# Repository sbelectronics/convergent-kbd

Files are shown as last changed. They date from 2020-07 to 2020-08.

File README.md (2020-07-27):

# PS2 Keyboard to Convergent Technologies NGEN Keyboard Adapter

Scott Baker, http://www.smbaker.com/

## Purpose

This is an adapter that lets you use a PS2 keyboard on a Convergent Technologies NGEN workstation. Most of these workstations date to the 80s or 90s. The keyboard interface is a 1200 baud serial protocol that is unique to this architecture, making it problematic to get these old computers working unless you also happen to have the appropriate keyboard.

This adapter allows you to use a PS2 keyboard, which are readily available.

## Convergent special-purpose function keys

The Convergent includes a series of special-purpose keys on the left side of the keyboard. These include keys like the "Help" key, the "Cancel" and "Finish" keys, "Action", etc. Most of these I've attempted to emulate with other keys on a 104 key PS2 keyboard.

I also added the ability to build the adapter with a set of 12 Cherry MX keys. This gives a more Convergent-like feel to the keyboard rather than trying to hunt down bizarre mappings on 104 key keyboard. These additional keys are entirely optional -- you can build the adapter with or without them.

## My first prototype, using ATTINY85

My first prototype used an ATTINY85 processor. I've kept the code in this repo for historical reasons. This adapter was compact, but had a few functionality issues due to the need to implement a software UART -- it was possible to hit the PS2 keyboard fast enough to eventually cause the serial and/or PS2 timing to glitch and register an incorrect keyboard event. Maybe with some work that would be fixable, but switching to a microcontroller with a real UART was a better solution.

## My second (and final) prototype using ATMEGA328

This version used an ATMEGA328, which has a hardware UART. Much simpler and more reliably than trying to make do with software UART. The 328 also has a number of additional GPIO, which I used to implement the 12 additional special-function keys. There were enough spare GPIO that I didn't bother to multiplex the keyboard scanning.

This is the prototype you want to build -- it's in the `convergent-keyboard-at328` directory.

## Fuses

Make sure to burn the fuses in addition to burning the code. The fuses are generally at the defaults with the exception of CKDIV8. There's a screenshot of the fuse settings in minipro.

## Schematics

The Schematics are in the schematics directory. My blog post at https://www.smbaker.com/restoring-a-convergent-technologies-ngen-pc-workstation-burroughs-b25-unisys has a lot more detail on the design work, both on the keyboard adapter and on a video adapter.

The schematics are checked in here into the "schematics" directory. You'll find two schematics, one for the adapter with 4 optional special-function keys, and another for an addon board that adds the remaining 8 special-function keys. As mentioned above, the keys are optional. This was split into two boards to make the board production cost-effective (two small boards can be ordered as "prototypes" whereas one large board must be ordered as production, from the board house that I use).

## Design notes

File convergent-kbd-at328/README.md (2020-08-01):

Board: Atmega328 on a breadboard

Makefile notes:
   Makefile is highly customized to my home setup.
   You'll need to update it for your paths.

   "make help"  -- shows the help
   "make show_boards" -- shows the boards
   "make" -- makes everything
   "make ispload" -- burns using the usbasp
   "make set_fuses" -- burns the fuses

   My arduino directory has "atmega328 on a breadboard" manually copied into the tree.

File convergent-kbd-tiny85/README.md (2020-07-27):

Board: AtTiny25/45/85
Chip: AtTiny85
Clock: 8Mhz (Excernal)    (should be internal??)
Bod Level: Bod Disabled
Save Eeprom: Eeporm retained
Timer 1 Clock: CPU
LTO: Disabled

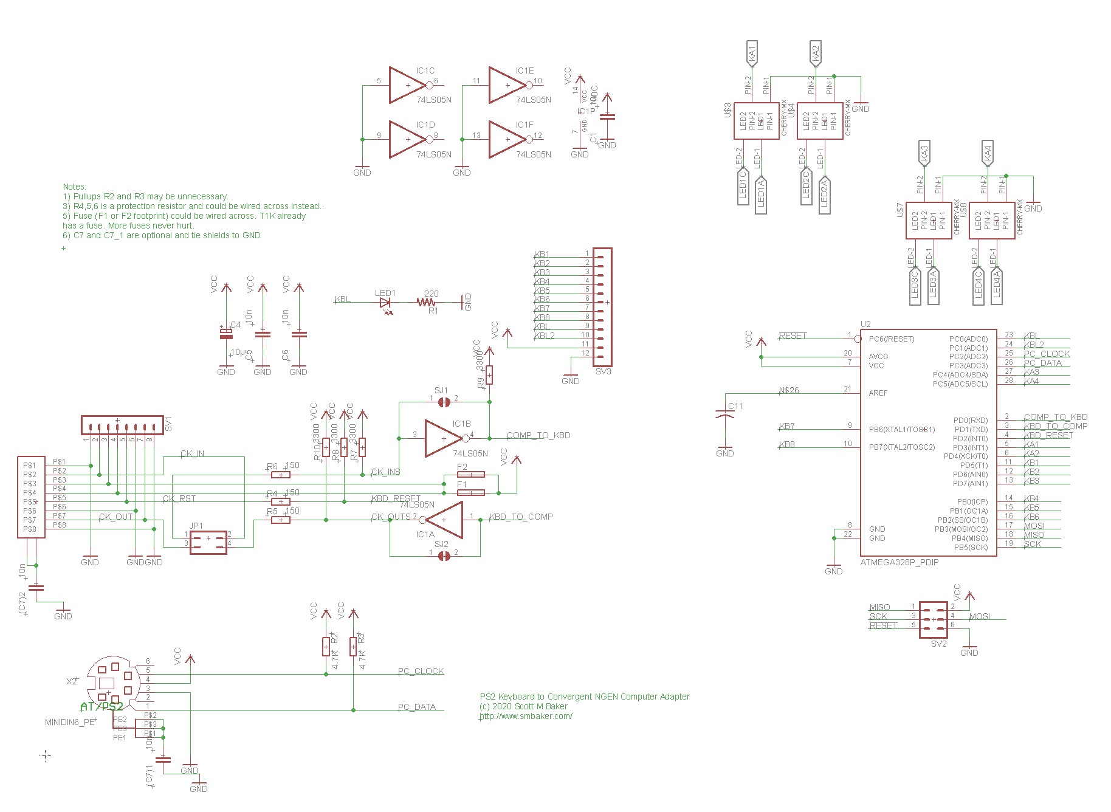
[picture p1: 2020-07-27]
schematics/convergent-keypad-at328-rev0.4.jpg

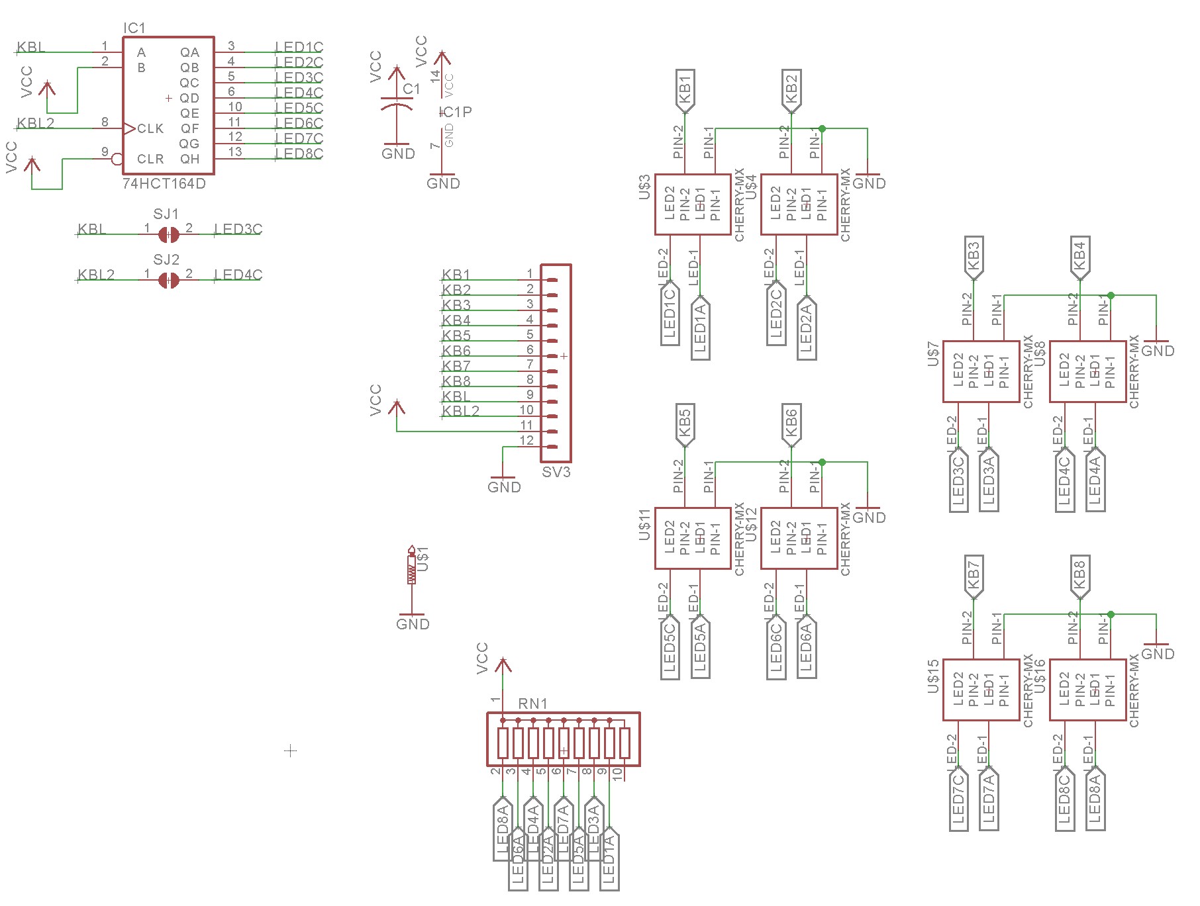
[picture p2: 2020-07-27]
schematics/8key-addon-schematic.jpg

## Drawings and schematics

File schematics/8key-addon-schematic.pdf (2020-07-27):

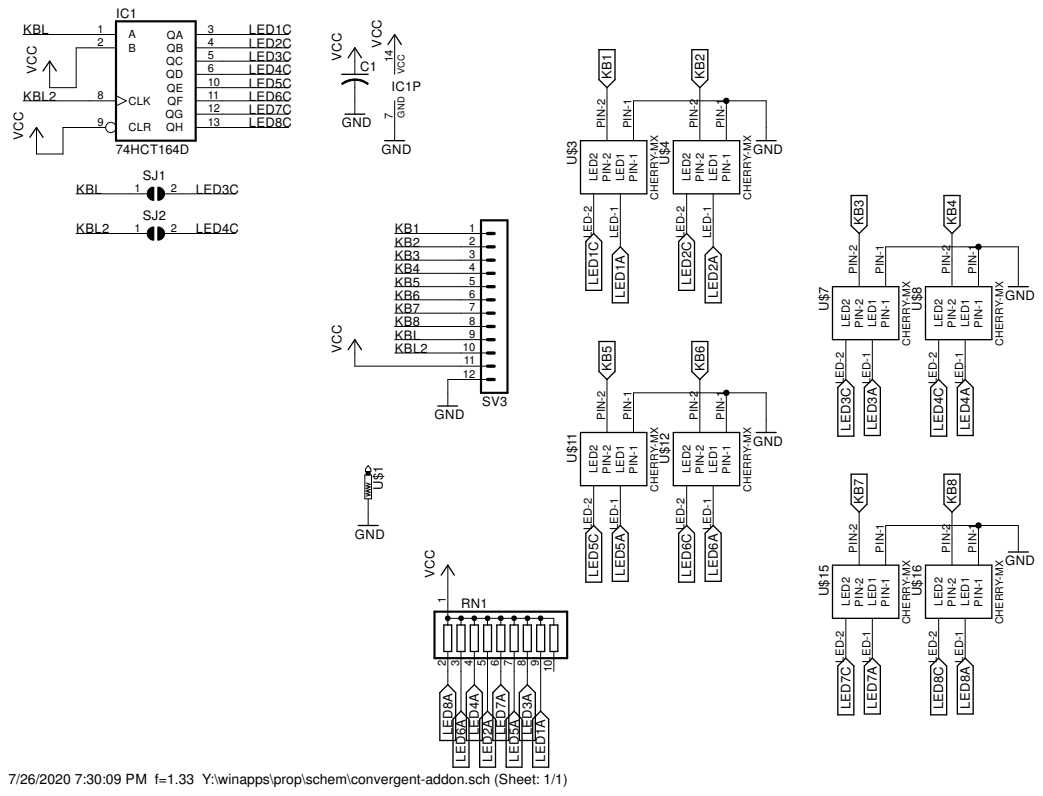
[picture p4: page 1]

7/26/2020 7:30:09 PM f=1.33 Y:\winapps\prop\schem\convergent-addon.sch (Sheet: 1/1)

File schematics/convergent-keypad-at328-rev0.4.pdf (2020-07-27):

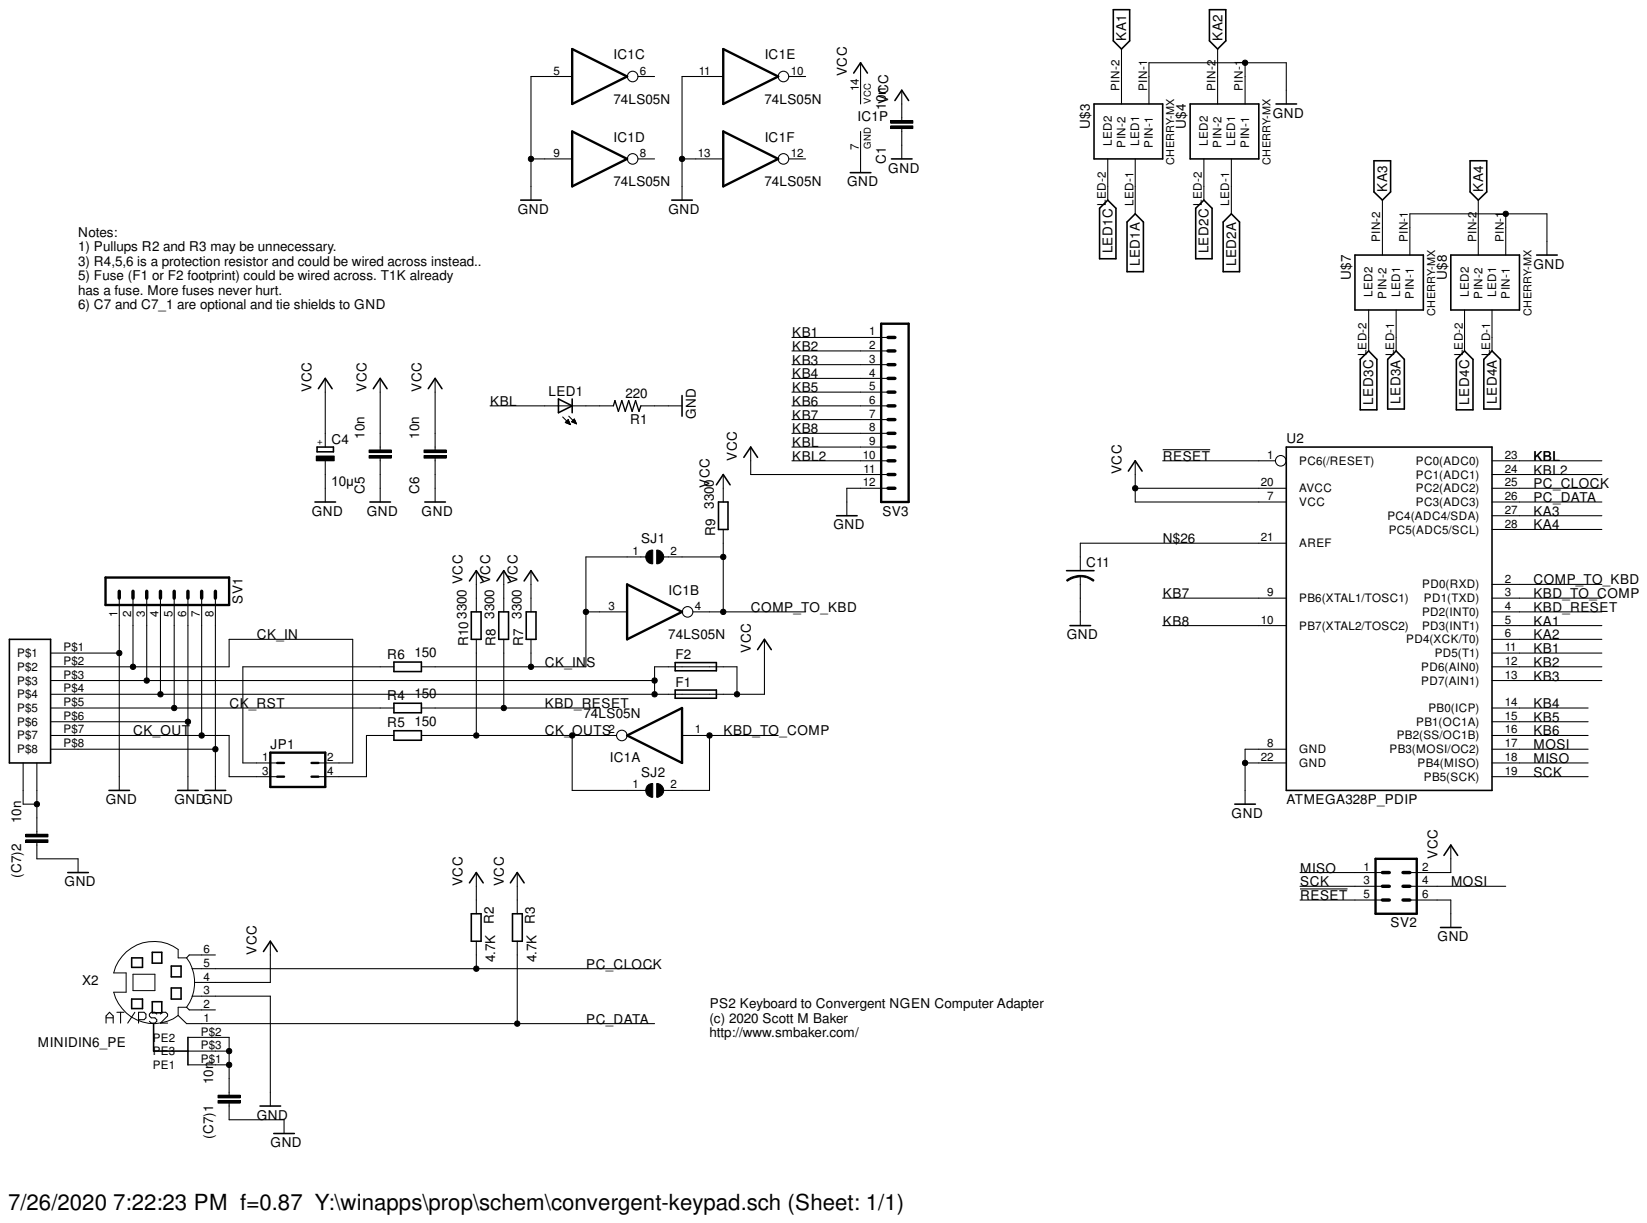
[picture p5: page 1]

Notes:
1) Pullups R2 and R3 may be unnecessary.
3) R4,5,6 is a protection resistor and could be wired across instead..
5) Fuse (F1 or F2 footprint) could be wired across. T1K already
has a fuse. More fuses never hurt.
6) C7 and C7_1 are optional and tie shields to GND

PS2 Keyboard to Convergent NGEN Computer Adapter
(c) 2020 Scott M Baker
http://www.smbaker.com/

7/26/2020 7:22:23 PM f=0.87 Y:\winapps\prop\schem\convergent-keypad.sch (Sheet: 1/1)

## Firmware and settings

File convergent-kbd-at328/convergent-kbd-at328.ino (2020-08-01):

/* 
 * convergent-kbd-tiny85.ino
 *
 * PS2 Keyboard on a Convergent NGEN.
 *
 * (c) Scott Baker, https://www.smbaker.com/
 */

// Some of the PS2 code originally based on keyboard.c
//   for NerdKits with ATmega168
//   hevans@nerdkits.com


#include <Arduino.h>

#include "convergent_scancode_map.h"
#include "keypad.h"


//PIN configuration
//PD2           -  NGEN Reset
//PD1           -  NGEN KBD_To_Comp
//PD0 (PCINT16) -  NGEN Comp_to_kbd
//PC2 (PCINT10) -  PS2 Keyboard CLK
//PC3           -  PS2 Keyboard DATA

#define CONVERGENT_TX_PIN PD1
#define CONVERGENT_RX_PIN PD0

#define CONVERGENT_RESET (1<<PD2)
#define CONVERGENT_TX (1<<CONVERGENT_TX_PIN)
#define CONVERGENT_RX (1<<CONVERGENT_RX_PIN)

#define PS2_INT PCINT10
#define PS2_CLK (1<<PC2)
#define PS2_DATA (1<<PC3)

#define PS2_CAPSLOCK_SCANCODE 0x58
#define PS2_NUMLOCK_SCANCODE 0x77
#define PS2_PAUSE_SCANCODE 0x77
#define PS2_BACKSLASH_SCANCODE 0x5D
#define PS2_LSHIFT_SCANCODE 0x12
#define PS2_RSHIFT_SCANCODE 0x59
#define PS2_BACKQUOTE_SCANCODE 0x0E

#define CAPSLOCK_LEDBIT 0x04
#define NUMLOCK_LEDBIT 0x02

#define SCANCODE_NONE 0xFF

volatile uint8_t kbd_data;
volatile uint8_t kbd_event;
volatile uint8_t ack_event, nak_event;
volatile uint8_t next_extended, e1flag;
volatile uint8_t key_state[16];
volatile uint8_t disable_isr;
volatile uint8_t shift_down;
uint8_t convergent_code;
uint8_t started;
uint8_t bit_count;
uint8_t shift;
uint8_t caps_lock;
uint8_t extended;
uint8_t release;
uint8_t capslock;
uint8_t numlock;
uint8_t ps2_argument;
uint8_t ps2_have_argument;
uint8_t last_reset;
uint8_t convergent_enabled;
uint8_t convergent_echo;

uint8_t convergent_map_code(uint8_t data, uint8_t extended);

ISR(PCINT1_vect)
{
  //make sure clock line is low, if not ignore this transition
  if(PINC & PS2_CLK) {
    return;
  }

  if (disable_isr) {
    return;
  }

  //if we have not started, check for start bit on DATA line
  if(!started){
    if ( (PINC & PS2_DATA) == 0 ) {
      started = 1;
      bit_count = 0;
      kbd_data = 0;
      //printf_P(PSTR("%d"),started);
      return;
    }
  } else if(bit_count < 8) { //we started, read in the new bit
    //put a 1 in the right place of kdb_data if PC2 is high, leave
    //a 0 otherwise
    if (PINC & PS2_DATA) {
      kbd_data |= (1<<bit_count);
    }
    bit_count++;
    return;
  } else if(bit_count == 8){ //pairty bit
    //not implemented
    bit_count++;
    return;
  } else {  //stop bit
    //should check to make sure DATA line is high, what to do if not?
    started = 0;
    bit_count = 0;
  }

  if(kbd_data == 0xF0){ //release code
    release = 1;
    kbd_data = 0;
    return;
  } else if (kbd_data == 0xFA) {
    ack_event = 1;
    return;
  } else if (kbd_data == 0xFE) {
    nak_event = 1;
    return;
  } else if (kbd_data == 0xE0) { //extended code
    next_extended = 1;
    return;
  } else if (kbd_data == 0xE1) { //the other extended code (pause/break)
    e1flag = 1;
    return;
  } else { //not a special character
    if ((e1flag) && (kbd_data!=0x77) && (kbd_data!=0x14)) {
      // E1,14,77,E1,F0,14,F0,77 is the pause sequence.
      // If we see something else, reset the flag.
      e1flag = 0;
    }
    if (release) { //we were in release mode - exit release mode
      if ((kbd_data == PS2_LSHIFT_SCANCODE) || (kbd_data == PS2_RSHIFT_SCANCODE)) {
          shift_down = 0;
      }
      release = 0;
      convergent_code = convergent_map_code(kbd_data, next_extended);
      next_extended = 0;
      if (convergent_code != SCANCODE_NONE) {
          uint8_t mask = 1<<(convergent_code & 0x07);
          key_state[convergent_code >> 3] &= ~mask;
          kbd_event = 1;
      }
    } else {
      convergent_code = convergent_map_code(kbd_data, next_extended);
      next_extended = 0;
      if (convergent_code != SCANCODE_NONE) {
          uint8_t mask = 1<<(convergent_code & 0x07);
          key_state[convergent_code >> 3] |= mask;
          kbd_event = 1;
      }
    }
  }
}

void led_init()
{
  // make pc5 an output
  DDRC |= (1<<PC0);
}

void led_on()
{
  PORTC |= (1<<PC0);
}

void led_off()
{
  PORTC &= ~(1<<PC0);
}

void init_keyboard()
{
  uint8_t i;

  for (i=0; i<16; i++) {
    key_state[i] = 0;
  }

  started = 0;
  kbd_data = 0;
  bit_count = 0;
  next_extended = 0;
  e1flag = 0;
  kbd_event = 0;
  disable_isr = 0;
  shift_down = 0;
  ps2_have_argument = 0;
  ack_event = 0;
  nak_event = 0;

  //make PS2_CLK input pin
  //DDRC &= ~PS2_CLK;
  //turn on pullup resistor
  PORTC |= PS2_CLK;
  
  //Set the mask on Pin change interrupt 1 so that ISR for PS2_CLK fires
  //the interrupt.
  PCMSK1 |= (1<<PS2_INT);
}

void init_isr()
{
  // Clear pin change interrupt flag.
  //PCIFR |= (1<<PCIF1);

  //Enable PIN Change Interrupt 1 - This enables interrupts on pins
  PCICR |= (1<<PCIE1);
}

uint8_t wait_for_bit(uint8_t bit, uint8_t highlow, uint16_t ms)
{
    if (highlow != LOW) {
      highlow = bit;
    }

    uint16_t i;
    for (i=0; i<ms*1000; i++) {
      if ((PINC & bit) == highlow) {
        return 1;
      }
      delayMicroseconds(1);
    }
    // timeout
    return 0;
}

uint8_t compute_parity(uint16_t n) 
{ 
    uint8_t parity = 0; 
    while (n) 
    { 
        parity = !parity; 
        n      = n & (n - 1); 
    }         
    return parity; 
} 

void ps2_clk_low()
{
  PORTC &= ~PS2_CLK;
  DDRC |= PS2_CLK;
}

void ps2_clk_release()
{
  // open-collector output; to set high we just release
  DDRC &= ~PS2_CLK;
}

void ps2_data_low()
{
  PORTC &= ~PS2_DATA;
  DDRC |= PS2_DATA;
}

void ps2_data_release()
{
  // open-collector output; to set high we just release
  DDRC &= ~PS2_DATA;
}

uint8_t ps2_send_byte(uint16_t b)
{
    int i;

    wait_for_bit(PS2_CLK, HIGH, 2);

    // bring clock low
    ps2_clk_low();
    // wait 100us
    delayMicroseconds(300);
    // bring data low
    ps2_data_low();
    delayMicroseconds(1);
    // return clock to input state
    ps2_clk_release();

    // wait for keyboard to bring clock low, up to 15ms
    if (!wait_for_bit(PS2_CLK, LOW, 15)) {
      ps2_data_release();
      return 0;
    }

    if (!compute_parity(b)) {
      b |= 0x100;
    }

    // 8 data bits + one parity bit, assume the parity is in bit position 8
    for (i=0; i<9; i++) {
      // set the data bit
      if ((b&1)==1) {
        ps2_data_release();
      } else {
        ps2_data_low();
      }
      // wait for clock to go high
      if (!wait_for_bit(PS2_CLK, HIGH, 2)) {
        ps2_data_release();
        return 0;
      }
      if (!wait_for_bit(PS2_CLK, LOW, 2)) {
        ps2_data_release();
        return 0;
      }
      b = b >> 1;
    }
    
    // return data to inptu state
    ps2_data_release();

    // wait for the ack
    if (!wait_for_bit(PS2_DATA, LOW, 2)) {
      return 0;
    }
    if (!wait_for_bit(PS2_CLK, LOW, 2)) {
      return 0;
    }

    return 1;
}

void ps2_send_command_argument(uint8_t command, uint8_t argument)
{
  disable_isr = 1;
  if (ps2_send_byte(command)) {
      ps2_argument = argument;
      ps2_have_argument = 1;
  }
  disable_isr = 0;
}

void ps2_send_argument(uint8_t arg)
{
  disable_isr = 1;
  ps2_send_byte(ps2_argument);
  disable_isr = 0;
}

void convergent_init()
{
  last_reset = (PIND & CONVERGENT_RESET);
  convergent_enabled = false;
  convergent_echo = false;
}

uint8_t convergent_map_code(uint8_t data, uint8_t extended)
{
    uint8_t scancode;

    if (data >= 128) {
        // Out of bounds of the scancode_map array.
        // Could be a control responds from the keyboard
        //    AA = BAT successful, etc
        return SCANCODE_NONE;
    }

    if (extended!=0) {
        scancode = pgm_read_byte(&(extcode_map[data]));
    } else {
        scancode = pgm_read_byte(&(scancode_map[data]));
    }

    // this should NOT happen.
    if (scancode >= 128) {
        return SCANCODE_NONE;
    }

    return scancode;
}

void convergent_send_packet()
{
  uint8_t i;
  uint8_t prev = SCANCODE_NONE;

  led_on();

  // The largest possible scancode is 127.
  
  for (i=0; i<128; i++) {
    uint8_t mask = 1<<(i & 0x07);
    if (((key_state[i>>3] & mask) != 0) || ((keypad_state[i>>3] & mask) !=0)) {
      if (prev!=SCANCODE_NONE) {
        Serial.write(prev);
      }
      prev = i;
    }
  }

  if (prev != SCANCODE_NONE) {
    // send the last key, with the high bit set to signal end of scan
    Serial.write(prev | 0x80);
  } else {
    // no keys down
    Serial.write(0xC0);
  }

  led_off();
}

void send_id_sequence()
{
  uint8_t i;

  led_on();

  for (i=0; i<120; i++) {
    Serial.write(0xFE);
  }
  // Even though we have only one port, diagnostics
  // will complain if we don't identify a keyboard
  // as dual-ported.
  Serial.write(0xB0); // keyboard, no boot request, dual-ported
  Serial.write(0x04); // K4 Keyboard

  convergent_enabled = false;
  convergent_echo = false;

  led_off();
}

void handle_serial_input(uint8_t b)
{
  if ((b == 0x92) && (convergent_echo)) {
    convergent_echo = false;
  }
  
  if (convergent_echo) {
    Serial.write(b);
    return;
  }
  
  switch (b) {
    case 0x92:
        // software reset
        convergent_enabled = true;
        // force a keyboard scan, should report C0
        kbd_event = 1;
        break;
    case 0x8C:
        // rom checksum test
        led_on();
        Serial.write(0xF0);
        led_off();
        break;
    case 0x9E:
        convergent_echo = true;
        break;
    default:
        break;
  }
}

void check_hardware_reset() {
  // hardware reset is on the transition from low to high
  uint8_t reset = (PIND & CONVERGENT_RESET);
  if (reset && (!last_reset)) {
    // reset went from low to high
    send_id_sequence();
  }
  last_reset = reset;
}

void setup() {
  init_isr();

  init_keyboard();

  convergent_init();

  keypad_init();

  Serial.begin(1200);

  led_init();

  //enable interrupts
  sei();

  send_id_sequence();
}

void loop() {
    check_hardware_reset();
    keypad_update();
    
    if (Serial.available() > 0) {
        handle_serial_input(Serial.read());  
    }
    
    if (kbd_event || keypad_event) {
        convergent_send_packet();
        kbd_event = 0;
        keypad_event = 0;
    }
    if (ack_event != 0) {
      if (ps2_have_argument) {
        ps2_send_argument(ps2_argument);
        ps2_have_argument = 0;
      }
      ack_event = 0;
    }
    if (nak_event != 0) {
        ps2_have_argument = 0;
        nak_event = 0;
    }
}

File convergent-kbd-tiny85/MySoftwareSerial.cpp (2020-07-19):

/*
MySoftwareSerial.cpp (formerly NewSoftSerial.cpp) -
Multi-instance software serial library for Arduino/Wiring
-- Interrupt-driven receive and other improvements by ladyada
   (http://ladyada.net)
-- Tuning, circular buffer, derivation from class Print/Stream,
   multi-instance support, porting to 8MHz processors,
   various optimizations, PROGMEM delay tables, inverse logic and
   direct port writing by Mikal Hart (http://www.arduiniana.org)
-- Pin change interrupt macros by Paul Stoffregen (http://www.pjrc.com)
-- 20MHz processor support by Garrett Mace (http://www.macetech.com)
-- ATmega1280/2560 support by Brett Hagman (http://www.roguerobotics.com/)

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
The latest version of this library can always be found at
http://arduiniana.org.
*/

// When set, _DEBUG co-opts pins 11 and 13 for debugging with an
// oscilloscope or logic analyzer.  Beware: it also slightly modifies
// the bit times, so don't rely on it too much at high baud rates
#define _DEBUG 0
#define _DEBUG_PIN1 11
#define _DEBUG_PIN2 13

#define LED_PIN (1<<PB5)
//
// Includes
//
#include <avr/interrupt.h>
#include <avr/pgmspace.h>
#include <Arduino.h>
#include "MySoftwareSerial.h"
#include <util/delay_basic.h>

//
// Statics
//
MySoftwareSerial *MySoftwareSerial::active_object = 0;
char MySoftwareSerial::_receive_buffer[_SS_MAX_RX_BUFF];
volatile uint8_t MySoftwareSerial::_receive_buffer_tail = 0;
volatile uint8_t MySoftwareSerial::_receive_buffer_head = 0;

//
// Debugging
//
// This function generates a brief pulse
// for debugging or measuring on an oscilloscope.
inline void DebugPulse(uint8_t pin, uint8_t count)
{
#if _DEBUG
  volatile uint8_t *pport = portOutputRegister(digitalPinToPort(pin));

  uint8_t val = *pport;
  while (count--)
  {
    *pport = val | digitalPinToBitMask(pin);
    *pport = val;
  }
#endif
}

//
// Private methods
//

/* static */
inline void MySoftwareSerial::tunedDelay(uint16_t delay) {
  _delay_loop_2(delay);
}

// This function sets the current object as the "listening"
// one and returns true if it replaces another
bool MySoftwareSerial::listen()
{
  if (!_rx_delay_stopbit)
    return false;

  if (active_object != this)
  {
    if (active_object)
      active_object->stopListening();

    _buffer_overflow = false;
    _receive_buffer_head = _receive_buffer_tail = 0;
    active_object = this;

    setRxIntMsk(true);
    return true;
  }

  return false;
}

// Stop listening. Returns true if we were actually listening.
bool MySoftwareSerial::stopListening()
{
  if (active_object == this)
  {
    setRxIntMsk(false);
    active_object = NULL;
    return true;
  }
  return false;
}

//
// The receive routine called by the interrupt handler
//
void MySoftwareSerial::recv()
{

#if GCC_VERSION < 40302
// Work-around for avr-gcc 4.3.0 OSX version bug
// Preserve the registers that the compiler misses
// (courtesy of Arduino forum user *etracer*)
  asm volatile(
    "push r18 \n\t"
    "push r19 \n\t"
    "push r20 \n\t"
    "push r21 \n\t"
    "push r22 \n\t"
    "push r23 \n\t"
    "push r26 \n\t"
    "push r27 \n\t"
    ::);
#endif

  uint8_t d = 0;

  PORTB |= LED_PIN;
  tunedDelay(100);
  PORTB &= (~LED_PIN);

  // If RX line is high, then we don't see any start bit
  // so interrupt is probably not for us
  if (_inverse_logic ? rx_pin_read() : !rx_pin_read())
  {
    // Disable further interrupts during reception, this prevents
    // triggering another interrupt directly after we return, which can
    // cause problems at higher baudrates.
    setRxIntMsk(false);

    // Wait approximately 1/2 of a bit width to "center" the sample
    tunedDelay(_rx_delay_centering);
    DebugPulse(_DEBUG_PIN2, 1);

    // Read each of the 8 bits
    for (uint8_t i=8; i > 0; --i)
    {
      tunedDelay(_rx_delay_intrabit);
      d >>= 1;
      DebugPulse(_DEBUG_PIN2, 1);
      if (rx_pin_read())
        d |= 0x80;
    }

    if (_inverse_logic)
      d = ~d;

    // if buffer full, set the overflow flag and return
    uint8_t next = (_receive_buffer_tail + 1) % _SS_MAX_RX_BUFF;
    if (next != _receive_buffer_head)
    {
      // save new data in buffer: tail points to where byte goes
      _receive_buffer[_receive_buffer_tail] = d; // save new byte
      _receive_buffer_tail = next;
    }
    else
    {
      DebugPulse(_DEBUG_PIN1, 1);
      _buffer_overflow = true;
    }

    // skip the stop bit
    tunedDelay(_rx_delay_stopbit);
    DebugPulse(_DEBUG_PIN1, 1);

    // Re-enable interrupts when we're sure to be inside the stop bit
    setRxIntMsk(true);

  }

#if GCC_VERSION < 40302
// Work-around for avr-gcc 4.3.0 OSX version bug
// Restore the registers that the compiler misses
  asm volatile(
    "pop r27 \n\t"
    "pop r26 \n\t"
    "pop r23 \n\t"
    "pop r22 \n\t"
    "pop r21 \n\t"
    "pop r20 \n\t"
    "pop r19 \n\t"
    "pop r18 \n\t"
    ::);
#endif
}

uint8_t MySoftwareSerial::rx_pin_read()
{
  return *_receivePortRegister & _receiveBitMask;
}

//
// Interrupt handling
//

/* static */
void MySoftwareSerial::handle_interrupt()
{
  if (active_object)
  {
    active_object->recv();
  }
}

//
// Constructor
//
MySoftwareSerial::MySoftwareSerial(uint8_t receivePin, uint8_t transmitPin, bool inverse_logic /* = false */) :
  _rx_delay_centering(0),
  _rx_delay_intrabit(0),
  _rx_delay_stopbit(0),
  _tx_delay(0),
  _buffer_overflow(false),
  _inverse_logic(inverse_logic)
{
  setTX(transmitPin);
  setRX(receivePin);
}

//
// Destructor
//
MySoftwareSerial::~MySoftwareSerial()
{
  end();
}

void MySoftwareSerial::setTX(uint8_t tx)
{
  // First write, then set output. If we do this the other way around,
  // the pin would be output low for a short while before switching to
  // output hihg. Now, it is input with pullup for a short while, which
  // is fine. With inverse logic, either order is fine.
  digitalWrite(tx, _inverse_logic ? LOW : HIGH);
  pinMode(tx, OUTPUT);
  _transmitBitMask = digitalPinToBitMask(tx);
  uint8_t port = digitalPinToPort(tx);
  _transmitPortRegister = portOutputRegister(port);
}

void MySoftwareSerial::setRX(uint8_t rx)
{
  pinMode(rx, INPUT);
  if (!_inverse_logic)
    digitalWrite(rx, HIGH);  // pullup for normal logic!
  _receivePin = rx;
  _receiveBitMask = digitalPinToBitMask(rx);
  uint8_t port = digitalPinToPort(rx);
  _receivePortRegister = portInputRegister(port);
}

uint16_t MySoftwareSerial::subtract_cap(uint16_t num, uint16_t sub) {
  if (num > sub)
    return num - sub;
  else
    return 1;
}

//
// Public methods
//
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

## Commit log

2020-07-19 dumping ground of initial efforts
2020-07-27 check in schematics
2020-07-27 schematics for 8key addon
2020-08-01 use arduino-mk
2020-08-01 prototype untested makefile for tiny85
2022-08-08 check in old gerbers, good luck sorting them out
    [convergent-adapter.GBL, convergent-adapter.GBO, convergent-adapter.GBS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]
